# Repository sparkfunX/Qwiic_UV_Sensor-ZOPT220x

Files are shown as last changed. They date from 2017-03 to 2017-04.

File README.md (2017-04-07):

Qwiic UV Sensor - ZZOPT2201
========================================

Qwiic UV Sensor

[*SPX-14264*](https://www.sparkfun.com/products/14264)

The ZOPT2201 is an excellent UVBS (ultraviolet energy sensor) in that it does true 310nm UVB sensing, not interpolated UV from ambient light like most sensors on the market. Without fuss or weird look up tables this sensor gives the current UV Index accurately.

The [Qwiic system](http://www.sparkfun.com/qwiic) enables fast and solderless connection between popular platforms and various sensors and actuators. You can read more about the Qwiic system [here](http://www.sparkfun.com/qwiic). 

License Information
-------------------

This product is _**open source**_!

Please review the LICENSE.md file for license information.

If you have any questions or concerns on licensing, please contact techsupport@sparkfun.com.

Distributed as-is; no warranty is given.

- Your friends at SparkFun.

_<COLLABORATION CREDIT>_

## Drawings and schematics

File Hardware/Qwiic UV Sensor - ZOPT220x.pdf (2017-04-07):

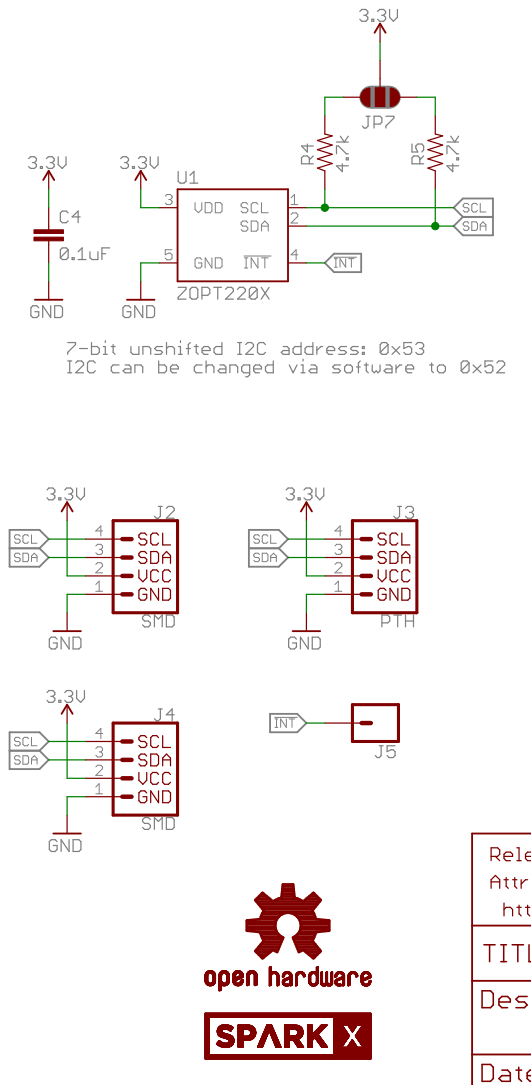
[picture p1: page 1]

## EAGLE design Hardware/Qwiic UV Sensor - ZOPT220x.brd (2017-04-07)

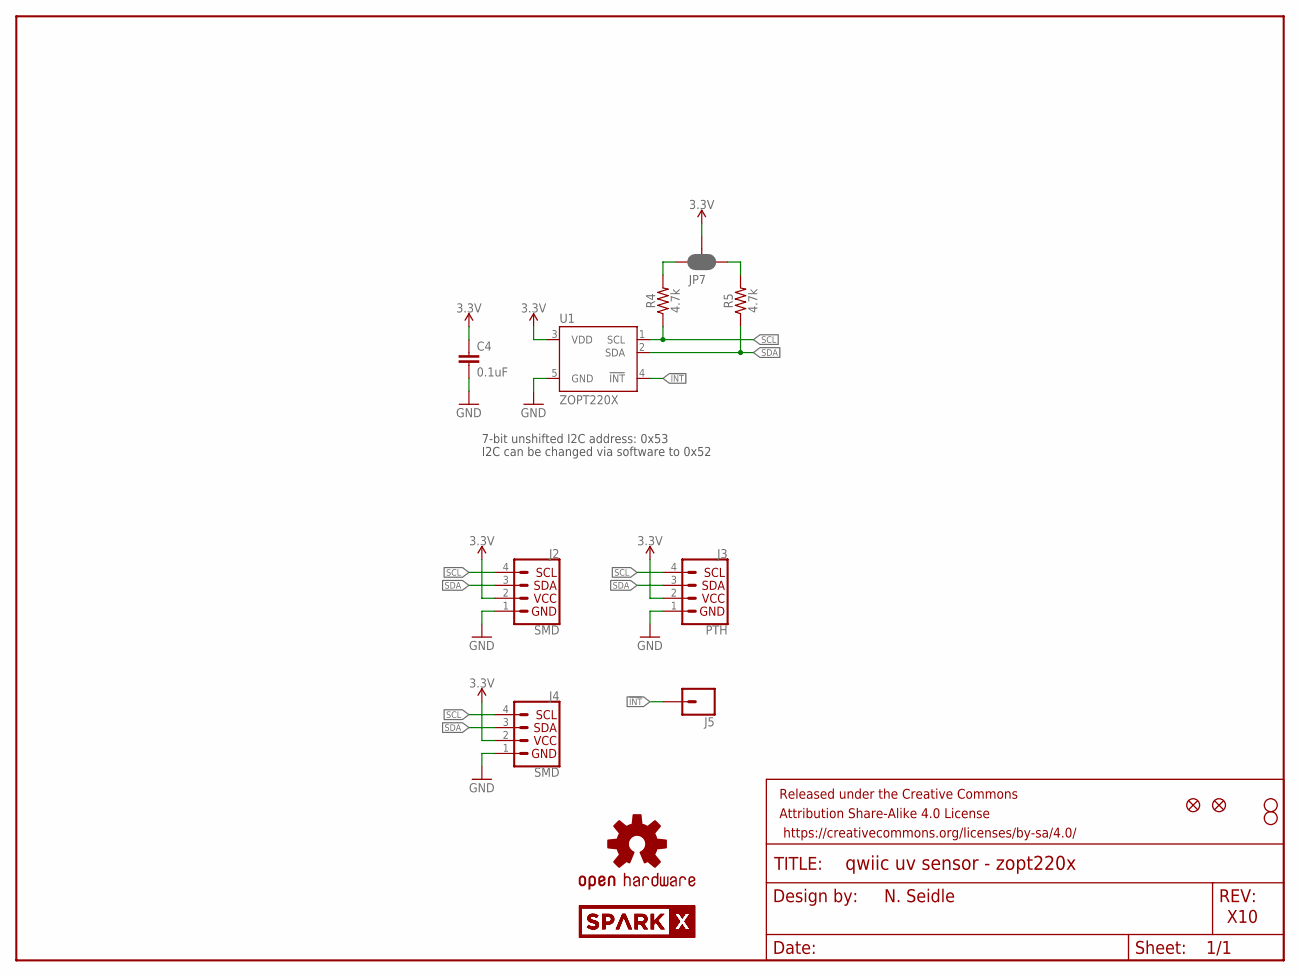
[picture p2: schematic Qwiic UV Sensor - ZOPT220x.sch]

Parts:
C4: 0.1uF; 0603
FRAME1: FRAME-LETTER; CREATIVE_COMMONS
J2, J4: SMD; 1X04_1MM_RA
J3: PTH; 1X04_NO_SILK
J5: CONN_01PTH_NO_SILK_YES_STOP; 1X01_NO_SILK
JP2, JP6: FIDUCIALUFIDUCIAL; MICRO-FIDUCIAL
JP3, JP4: STAND-OFF
JP7: JUMPER-SMT_3_2-NC_PASTE_SILK; SMT-JUMPER_3_2-NC_PASTE_SILK
LOGO1: OSHW-LOGOMINI; OSHW-LOGO-MINI
R4, R5: 4.7k; 0603
U1: ZOPT220X; LGA6
U$1, U$2: SPARKX-LOGO4; SPARKX-MEDIUM

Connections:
3.3V: C4.1, J2.2 (VCC), J3.2 (VCC), J4.2 (VCC), JP7.2, U1.3 (VDD)
!INT: J5.1, U1.4 (!INT)
GND: C4.2, J2.1 (GND), J3.1 (GND), J4.1 (GND), U1.5 (GND)
unnamed: JP7.1, R5.2
unnamed: JP7.3, R4.2
SCL: J2.4 (SCL), J3.4 (SCL), J4.4 (SCL), R4.1, U1.1 (SCL)
SDA: J2.3 (SDA), J3.3 (SDA), J4.3 (SDA), R5.1, U1.2 (SDA)

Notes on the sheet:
N. Seidle
X10
7-bit unshifted I2C address: 0x53
I2C can be changed via software to 0x52

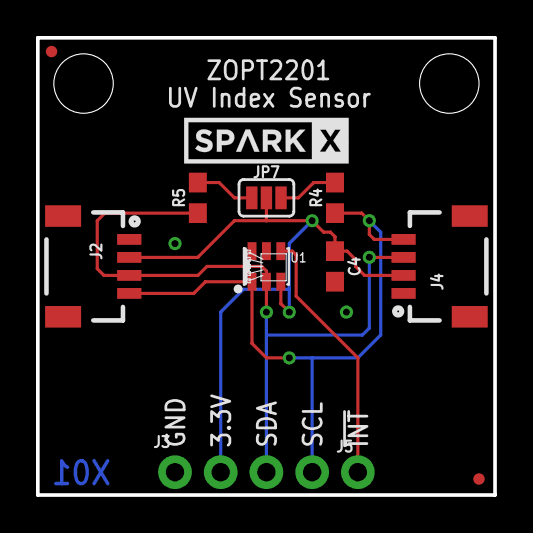
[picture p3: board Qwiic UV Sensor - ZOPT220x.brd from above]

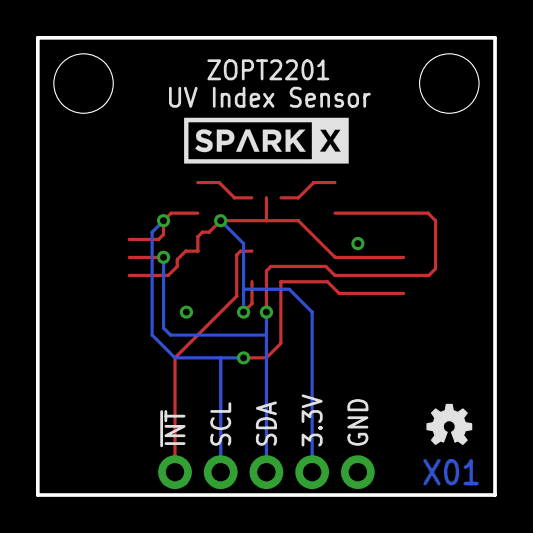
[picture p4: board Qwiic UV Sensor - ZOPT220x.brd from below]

Board: 2 copper layers, 25.4 x 25.4 mm, 17 parts (2 on the bottom side), 7 nets.

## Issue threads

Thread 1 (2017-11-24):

Run ZOPT2201 on Raspberry Pi 3 model B?

zack4m, 2017-11-24:
Will you release any drivers for Raspberry Pi? I have model 3 B and I bought this sensor assuming drivers will be available but I cannot find them. I attempted to install the ino files but no success.

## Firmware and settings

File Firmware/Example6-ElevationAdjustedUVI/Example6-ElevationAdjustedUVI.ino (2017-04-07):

/*
  Using the ZOPT220x UV Sensor
  By: Nathan Seidle
  SparkFun Electronics
  Date: April 4th, 2017
  License: This code is public domain but you buy me a beer if you use this and we meet someday (Beerware license).

  UV is very sensitive to the elevation of the sun.
  Given a lat, long, day, hour, minute, get a very accurate, adjusted UV Index.

  The ZOPT2201 sensor detects UVB + Ambient Light Sensor (ALS)
  The ZOPT2202 sensor detects UVA + UVB

  Hardware Connections:
  Attach the Qwiic Shield to your Arduino/Photon/ESP32 or other
  Plug the ZOPT220x onto the shield
  Serial.print it out at 115200 baud to serial monitor.

  Available:
  enableALSSensing() //ALS + COMP channels activated
  enableUVBSensing() //UVB + UV_COMP channels activated
  enableRawSensing() //ALS and UVB but no temperature compensation
  long getUVB()
  long getALS()
  setMeasurementRate(byte) 0 to 7
  setResolution(byte) 0 to 5
  setGain(byte) 0 to 4
  enableSensor()
  disableSensor()
  dataAvailable()
  checkPowerOnStatus()
  softReset()
  setI2CAdr52() //Set I2C address to 0x52
  setI2CAdr53() //Set I2C address to 0x53

*/

#include <Wire.h>

void setup()
{
  Serial.begin(9600);
  while (!Serial);
  Serial.println("ZOPT220x Read Example");

  Wire.begin();

  if (zopt220xSetup() == false)
  {
    Serial.println("Sensor failed to respond. Check wiring.");
    while (1); //Freeze!
  }
  Serial.println("ZOPT220x online!");

  enableUVBSensing(); //UVB + UV_COMP channels activated
}

byte hour = 3 + 12; //3PM
byte minute = 28;

void loop()
{
  if (dataAvailable())
  {
    //April 7th, 2017 3:28PM
    int day = 97; //Jan 01 = 1. From: https://www.epochconverter.com/daynumbers
    hour++;
    minute++;

    //Obtained from google maps. Right click on map -> What's here? gives lat/long of SparkFun HQ
    //Must be in degrees
    float latitude = 40.090579; //N is positive
    float longitude = -105.184831; //W is negative

    float elevationAdjustedUVIndex = getElevationAdjustedUVIndex(latitude, longitude, day, hour, minute);

    Serial.print("Elevation adjusted UV Index: ");
    Serial.print(elevationAdjustedUVIndex);

    long uvb = getUVB();
    Serial.print("UVB: ");
    Serial.print(uvb);

    Serial.println();
  }

  delay(1);
}

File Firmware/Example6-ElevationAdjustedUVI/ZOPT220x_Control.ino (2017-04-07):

byte zoptAddress = 0x53; //Default I2C address. Can be changed via software.
//#define ZOPT220X_ADDR 0x53 //7-bit unshifted default I2C Address
//#define ZOPT220X_ADDR 0x52 //7-bit unshifted programmed NVM I2C Address (in case you need multiple on same bus)

//Register addresses
#define ZOPT220x_MAIN_CTRL 0x00
#define ZOPT220x_LS_MEAS_RATE 0x04
#define ZOPT220x_LS_GAIN 0x05
#define ZOPT220x_PART_ID 0x06
#define ZOPT220x_MAIN_STATUS 0x07
#define ZOPT220x_ALS_DATA 0x0D
#define ZOPT220x_UVB_DATA 0x10
#define ZOPT220x_UV_COMP_DATA 0x13
#define ZOPT220x_COMP_DATA 0x16
#define ZOPT220x_INT_CFG 0x19
#define ZOPT220x_INT_PST 0x1A
#define ZOPT220x_DEVICE_CONFIG 0x2F
#define ZOPT220x_SPECIAL_MODE_1 0x30
#define ZOPT220x_SPECIAL_MODE_2 0x31

#define SENSORTYPE_ZOPT2201 0xB2
#define SENSORTYPE_ZOPT2202 0xB2 //Really IDT!? You didn't use a different part number for different parts?

//Setup the sensor with default settings
//Assume we are using the default zopt address of 0x53
boolean zopt220xSetup()
{
  boolean result = zopt220xSetupWithAddress(zoptAddress); //Assume the default address
  return (result);
}

//Attempts to talk to sensor. Returns false if sensor is not found
//If found, sets the sensor up with default UVB settings
//Call this function if you've changed the zopt I2C address
boolean zopt220xSetupWithAddress(byte address)
{
  zoptAddress = address; //Do all the zopt I2C communications at this address
  
  byte deviceID = zoptReadRegister(ZOPT220x_PART_ID);
  if (deviceID != 0xB2)
  {
    Serial.print("ID should be 0xB2. We heard 0x");
    Serial.println(deviceID, HEX);
    return (false);
  }

  checkPowerOnStatus(); //Read the POS bit to clear it

  setMeasurementRate(2); //100ms default
  setResolution(0); //20 bit, 400ms, needed for best UVI calculations
  setGain(4); //Default for UVB

  return (true);
}

//Return the current UV index
//Assumes UVB sensor has been setup with default settings
float getUVIndex(void)
{
  byte counter = 0;
  while(!dataAvailable())
  {
    delay(10);
    if(counter++ > 50) //We should have a reading in 400ms
    {
      //We've timed out waiting for the data. Return error
      return(-1.0);
    }
  }

  long uvb = getUVB(); //Get new data
  float uvIndex = getAdjustedUVIndex(uvb, 4, 0, 1.0); //Assumes default for UVI of gain:4, resolution:0, uviCorrection of 1.0
  return(uvIndex);
}

//Given UVB reading, and gain and resolution settings, outputs UV index
//From App note UV Index Calculation from IDT
float getAdjustedUVIndex(long UVB, byte gain, byte resolution, float uviCorrection)
{
  byte gainMode = 0; //gain is 0 to 4, gainMode is mapped 1 to 18
  byte resolutionMode = 0; //resolution is 0 to 5, resolutionMode is mapped 20bit to 13bit

  //Convert the 5 gain settings to gainMode
  switch (gain)
  {
    case 0: gainMode = 1; break;
    case 1: gainMode = 3; break;
    case 2: gainMode = 6; break;
    case 3: gainMode = 9; break;
    case 4: gainMode = 18; break;
    default: gainMode = 18; break; //Unknown state
  }

  //Convert the 6 resolution settings to resolutionMode
  switch (resolution)
  {
    case 0: resolutionMode = 20; break; //20-bit
    case 1: resolutionMode = 19; break;
    case 2: resolutionMode = 18; break;
    case 3: resolutionMode = 17; break;
    case 4: resolutionMode = 16; break;
    case 5: resolutionMode = 13; break; //13-bit
    default: resolutionMode = 20; break; //Unknown state
  }

  long uvAdjusted = 18 / gainMode * pow(2, 20 - resolutionMode) * UVB;

  float uvIndex = uvAdjusted / (5500.0 * uviCorrection);

  return(uvIndex);
}

//Returns the current UV data with temp compensation applied
//Assumes LS data bit 3 has been set (MAIN_STATUS)
//Poll dataAvailable() before calling this function
long getUVB() 
{
  return (zoptRead3Registers(ZOPT220x_UVB_DATA));
}

//Returns the current Ambient Light data with temp compensation applied
//Assumes data is available (LS data bit 3 has been set in MAIN_STATUS)
//Poll dataAvailable() before calling this function
long getALS() 
{
  return (zoptRead3Registers(ZOPT220x_ALS_DATA));
}

//Set the measurement rate
//0 = 25ms per measurement
//1 = 50ms
//2 = 100ms (default)
//3 = 200ms
//4 = 500ms
//5 = 1000ms
//6 = 2000ms
//7 = 2000ms
void setMeasurementRate(byte rate)
{
  if (rate > 7) rate = 7; //Error check

  //Read, set, write
  byte value = zoptReadRegister(ZOPT220x_LS_MEAS_RATE); //Read
  value &= ~(0b00000111); //Clear bits 2/1/0
  value |= rate; //Mask in rate
  zoptWriteRegister(ZOPT220x_LS_MEAS_RATE, value); //Write
}

//Set the measurement resolution
//0 = 20 bit / 400ms
//1 = 19 bit / 200ms
//2 = 18 bit / 100ms (default)
//3 = 17 bit / 50ms
//4 = 16 bit / 25ms
//5 = 13 bit / 3.125ms
void setResolution(byte resolution)
{
  if (resolution > 5) resolution = 5; //Error check

  //Read, set, write
  byte value = zoptReadRegister(ZOPT220x_LS_MEAS_RATE); //Read
  value &= ~(0b01110000); //Clear bits 6/5/4
  value |= (resolution << 4); //Mask in resolution
  zoptWriteRegister(ZOPT220x_LS_MEAS_RATE, value); //Write
}

//Set the gain for the sensor
//Different for ALS and UVB. It depends which mode you're in. See datasheet for info.
//0 = Gain 1
//1 = Gain 3 (default)
//2 = Gain 6
//3 = Gain 9
//4 = Gain 18 (recommended for UBV)
void setGain(byte gain)
{
  if (gain > 4) gain = 4; //Error check

  //Read, set, write
  byte value = zoptReadRegister(ZOPT220x_LS_GAIN); //Read
  value &= ~(0b00000111); //Clear bits 2/1/0
  value |= gain; //Mask in gain
  zoptWriteRegister(ZOPT220x_LS_GAIN, value); //Write
}

//Returns true if Bit 5 is set
boolean checkPowerOnStatus()
{
  byte value = zoptReadRegister(ZOPT220x_MAIN_STATUS); //Read
  if (value & 1 << 5) return (true);
  return (false);
}

//Check if new data is available
//Returns true if Bit 3 is set
boolean dataAvailable()
{
  byte value = zoptReadRegister(ZOPT220x_MAIN_STATUS); //Read
  if (value & 1 << 3) return (true);
  return (false);
}

//Turns on sensor
//Sets LS_EN bit
void enableSensor(void)
{
  //Read, set, write
  byte value = zoptReadRegister(ZOPT220x_MAIN_CTRL); //Read
  value |= (1 << 1); //Set LS_EN bit
  zoptWriteRegister(ZOPT220x_MAIN_CTRL, value); //Write
}

//Turns off sensor
//Clears LS_EN bit
void disableSensor(void)
{
  //Read, set, write
  byte value = zoptReadRegister(ZOPT220x_MAIN_CTRL); //Read
  value &= ~(1 << 1); //Clear LS_EN bit
  zoptWriteRegister(ZOPT220x_MAIN_CTRL, value); //Write
}

void standby() {
  setMode(1);  //Turn off everything and standby for I2C
}
void enableALSSensing() {
  setMode(2);  //ALS + COMP channels activated
}
void enableUVBSensing() {
  setMode(3);  //UVB + UV_COMP channels activated
}
void enableRawSensing() {
  setMode(4);  //Special mode: ALS+UVB+UV_COMP+COMP channels activated
}
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

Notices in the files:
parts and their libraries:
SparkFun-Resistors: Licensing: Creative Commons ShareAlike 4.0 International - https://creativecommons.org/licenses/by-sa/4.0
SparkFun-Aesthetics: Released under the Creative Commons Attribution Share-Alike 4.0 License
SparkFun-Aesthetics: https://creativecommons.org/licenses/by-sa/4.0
